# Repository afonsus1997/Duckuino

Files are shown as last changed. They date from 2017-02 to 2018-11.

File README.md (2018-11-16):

# 

### The truly open-source atmega32u4 ducky clone (V2.0)

## Info

Enter the duckuino, the fully open-source USB rubberducky clone based on the atmega32u4

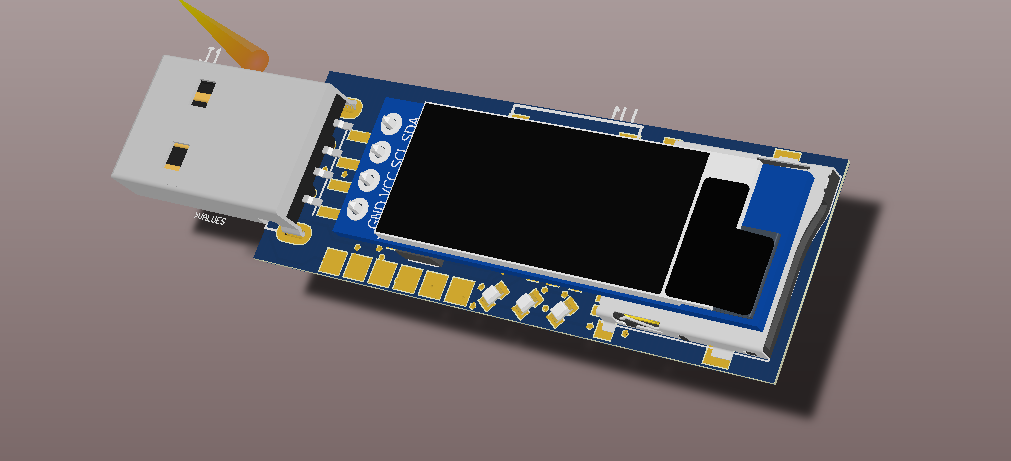
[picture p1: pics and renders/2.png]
Altium


## BOM

## PINMAP
PINMAP of the ATMEGA32u4

| PIN | ALT FUNCTION | OLED | Thumbwheel | LEDs | DIP Sw's | SD |
|:---:|:---:|:----:|:---:|:----:|:---:|:---:|
| D2  | SDA |  SDA | - | -  | - | - |
| D3  | SCL |  SCL | - | -  | - | - |
| D4  | A6 | -  | - | -  | - | CD/DAT3 (!CS!) |
| D5  | - | -  | - | -  | 4 | - |
| D6  | A7 | -  | - | LED1 | - | - |
| D7  | - | -  | - | LED2 | - | - |
| D8  | A8 | -  | Center | -  | - | - |
| D9  | A9 | -  | - | -  | 1 (Boot) | - |
| D10 | A10 | -  | - | -  | 2 | - |
| D11 | - | -  | Right | -  | - | - |
| D12 | - | -  | Left | -  | - | - |
| D13 | - | -  | - | -  | 3 | - |
| D14 | - | -  | - | -  | - | DAT0 (D0) |
| D15 | - | -  | - | -  | - | CLK (SCLK) |
| D16 | - | -  | - | -  | - | CMD (DI) |

## Renders & Pictures

### V2.0 Altium Renders

Altium

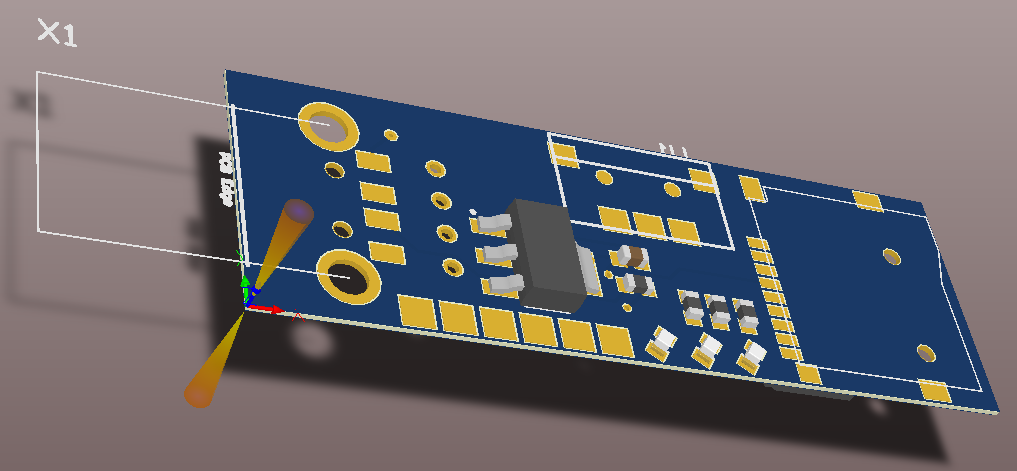
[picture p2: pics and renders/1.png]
Altium2


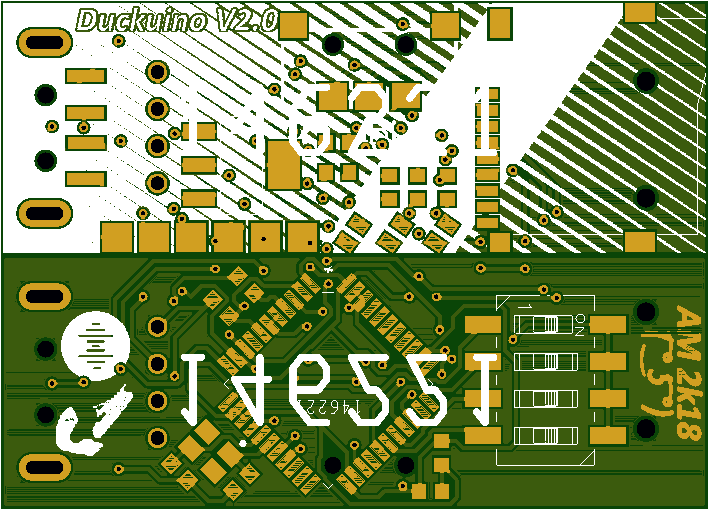
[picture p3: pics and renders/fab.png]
Fab


## Old Version Renders & Pictures

### V0.1 Photos
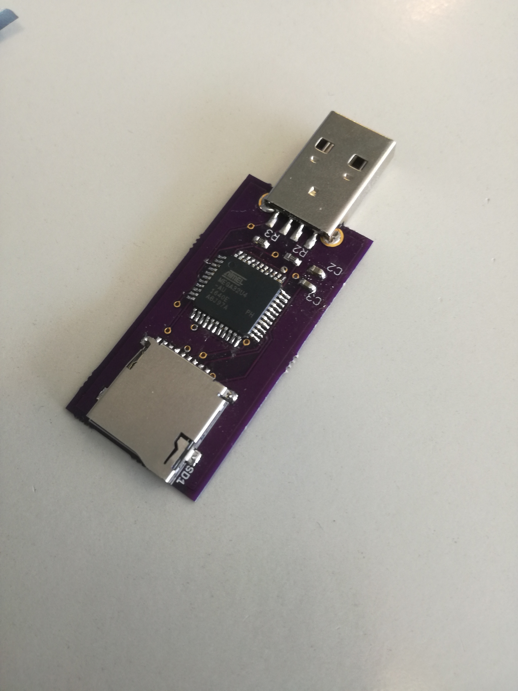
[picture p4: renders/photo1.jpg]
Soldered1


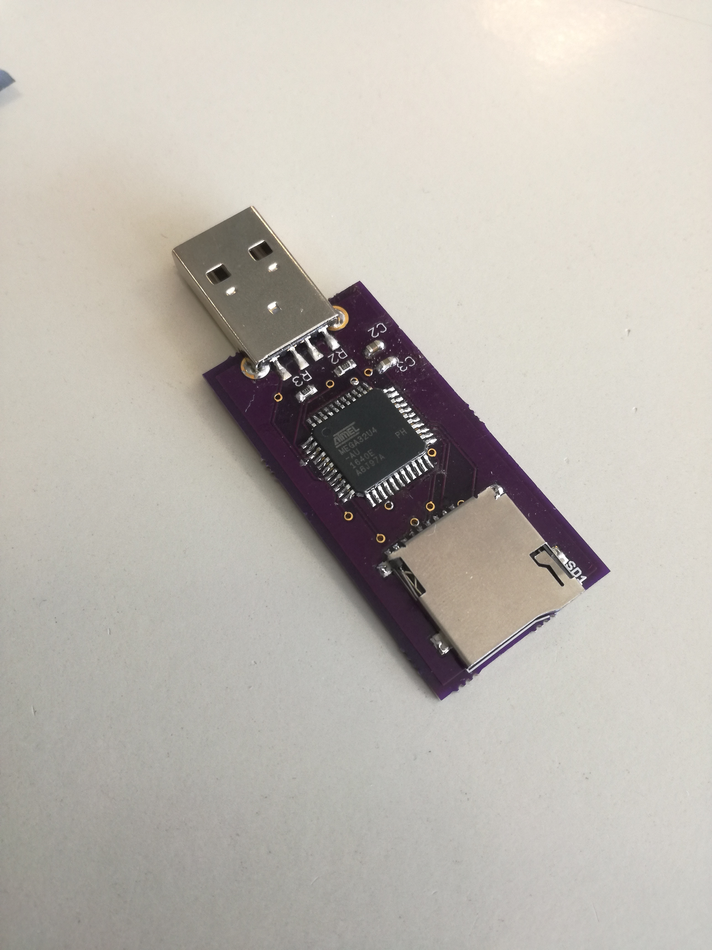
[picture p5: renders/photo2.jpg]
Soldered2


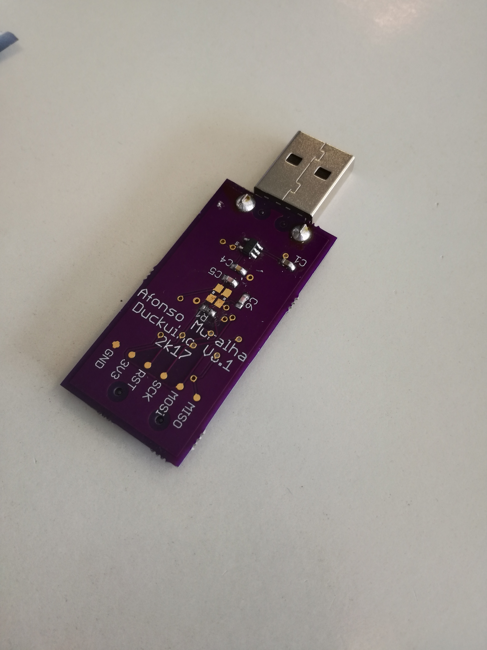
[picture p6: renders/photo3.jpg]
Soldered3


### V0.1 Renders
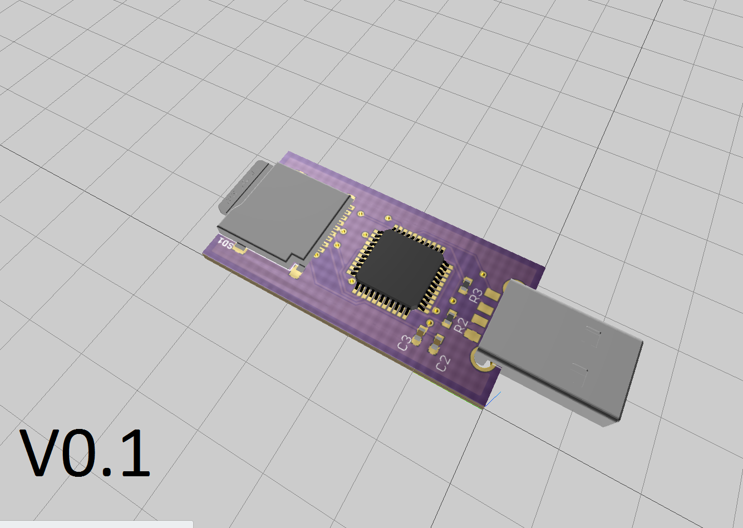
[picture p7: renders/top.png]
Render1


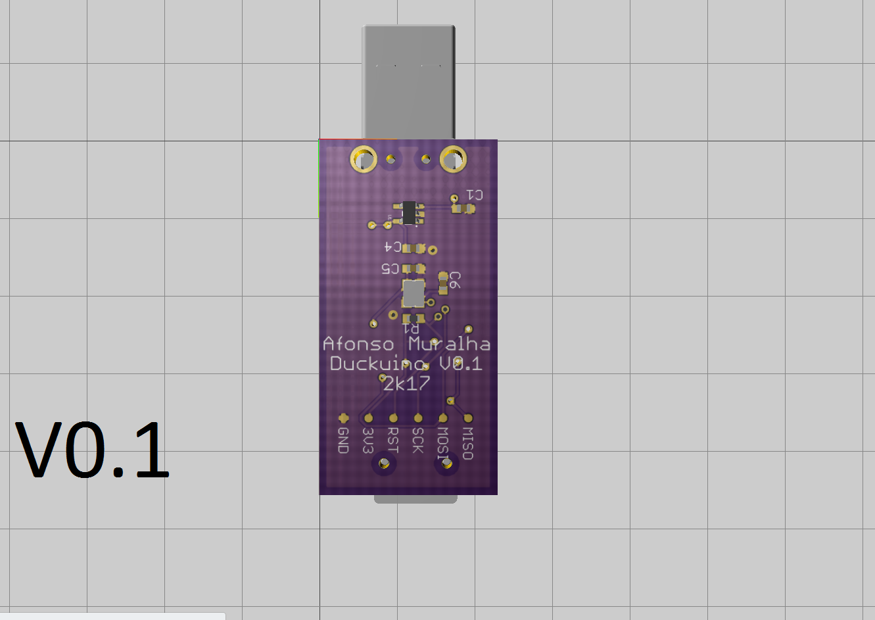
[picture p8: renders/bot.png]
Render2


### V0.1 Eagle Renders
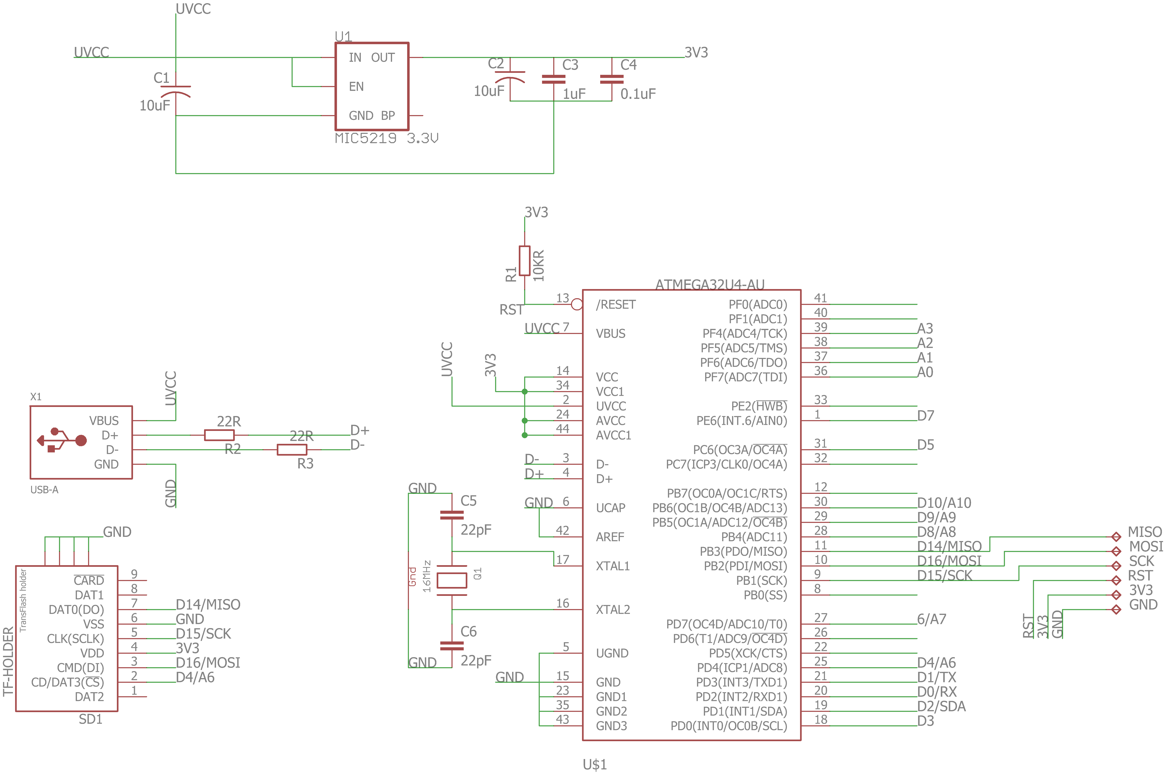
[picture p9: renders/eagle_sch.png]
Eagle1


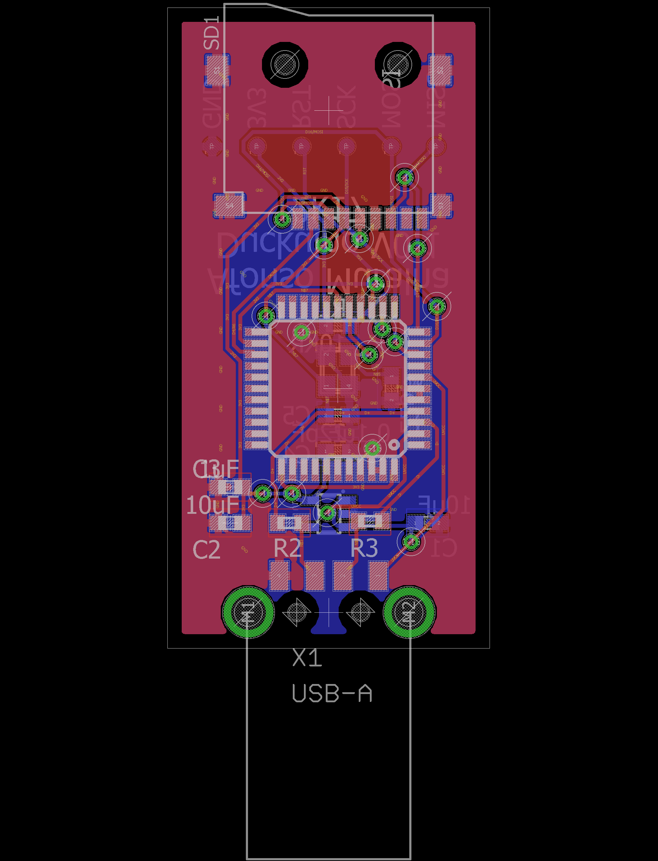
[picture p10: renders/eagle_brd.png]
Eagle2


### V0.1 PCB pictures
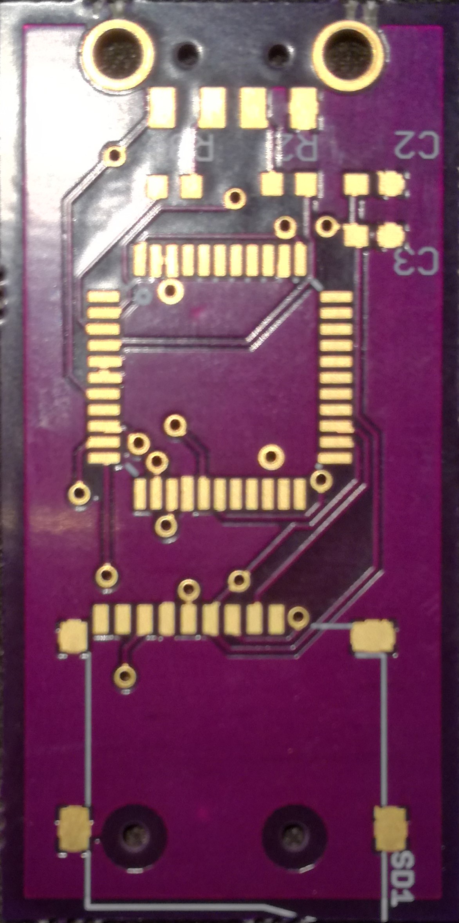
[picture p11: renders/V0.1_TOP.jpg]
PCB1
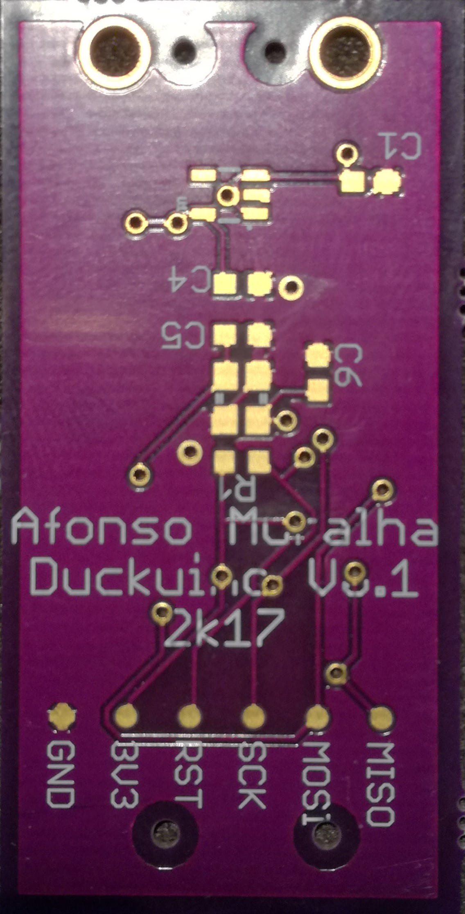
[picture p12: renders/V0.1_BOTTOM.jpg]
PCB2


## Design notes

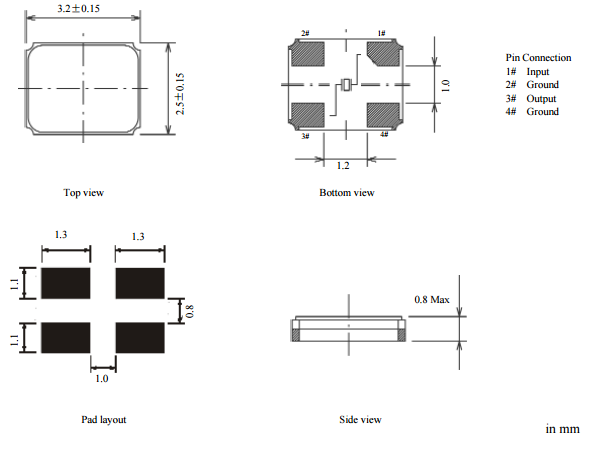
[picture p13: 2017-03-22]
XTALpinout.png

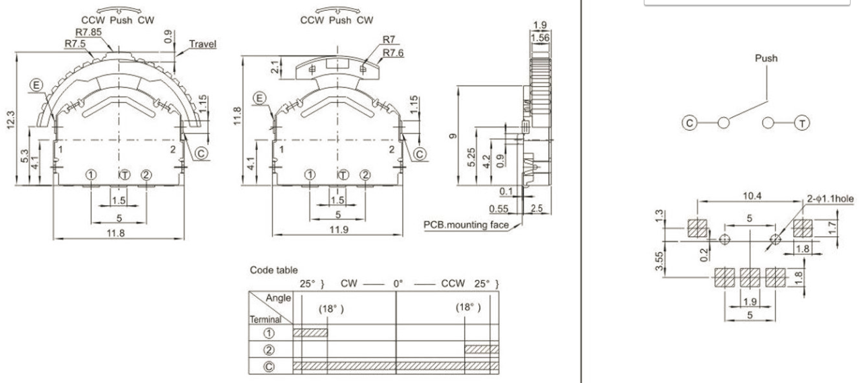
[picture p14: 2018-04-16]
slide pinout.png

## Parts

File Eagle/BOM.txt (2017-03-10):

Duckuino BOM

Part Value         Device            Package                                                                                                            
3V3  TPTP11R       TPTP11R           TP11R                                                                                                               
C1   10uF          C-USC0603         C0603                                                                                                         
C2   10uF          C-USC0603         C0603                                                                                                            
C3   1uF           C-EUC0603         C0603                                                                                                          
C4   0.1uF/100nF   C-EUC0603         C0603                                                                                                             
C5   22pF          C-EUC0603         C0603                                                                                                           
C6   22pF          C-EUC0603         C0603                                                                                                                                                                                                                              
Q1   16MHz         XTAL-4-3225       NX3225                                                                                                    
R1   10KR          RR0603            R0603                                                                                                               
R2   22R           RR0603            R0603                                                                                                              
R3   22R           RR0603            R0603                                                                                                                                                                                                                               
SD1  TF-HOLDER     TF-HOLDER         TF-PULL         
U$1  ATMEGA32U4-AU ATMEGA32U4-AU     TQFP44                                                                                                
U1   MIC5219 3.3V  V_REG_MIC52193.3V SOT23-5                                                                                                                      
X1   USB-A         USB-A

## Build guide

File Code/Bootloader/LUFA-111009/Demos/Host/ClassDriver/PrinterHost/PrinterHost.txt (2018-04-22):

/** \file
 *
 *  This file contains special DoxyGen information for the generation of the main page and other special
 *  documentation pages. It is not a project source file.
 */

/** \mainpage Printer Host Demo
 *
 *  \section Sec_Compat Demo Compatibility:
 *
 *  The following list indicates what microcontrollers are compatible with this demo.
 *
 *  - Series 7 USB AVRs (AT90USBxxx7)
 *
 *  \section Sec_Info USB Information:
 *
 *  The following table gives a rundown of the USB utilization of this demo.
 *
 *  <table>
 *   <tr>
 *    <td><b>USB Mode:</b></td>
 *    <td>Host</td>
 *   </tr>
 *   <tr>
 *    <td><b>USB Class:</b></td>
 *    <td>Printer Device</td>
 *   </tr>
 *   <tr>
 *    <td><b>USB Subclass:</b></td>
 *    <td>Bidirectional Protocol</td>
 *   </tr>
 *   <tr>
 *    <td><b>Relevant Standards:</b></td>
 *    <td>USBIF Printer Class Specification \n
 *        PCL Language Specification</td>
 *   </tr>
 *   <tr>
 *    <td><b>Usable Speeds:</b></td>
 *    <td>Low Speed Mode \n
 *        Full Speed Mode</td>
 *   </tr>
 *  </table>
 *
 *  \section Sec_Description Project Description:
 *
 *  Printer host demonstration application. This gives a simple reference
 *  application for implementing a USB Printer host, for USB printers using
 *  the bidirectional data encapsulation protocol and PCL language.
 *
 *  Upon connection of a compatible printer, the printer's device ID is sent
 *  to the AVR's serial port, and a simple test page is printed using the PCL
 *  printer language.
 *
 *  \section Sec_Options Project Options
 *
 *  The following defines can be found in this demo, which can control the demo behaviour when defined, or changed in value.
 *
 *  <table>
 *   <tr>
 *    <td>
 *     None
 *    </td>
 *   </tr>
 *  </table>
 */

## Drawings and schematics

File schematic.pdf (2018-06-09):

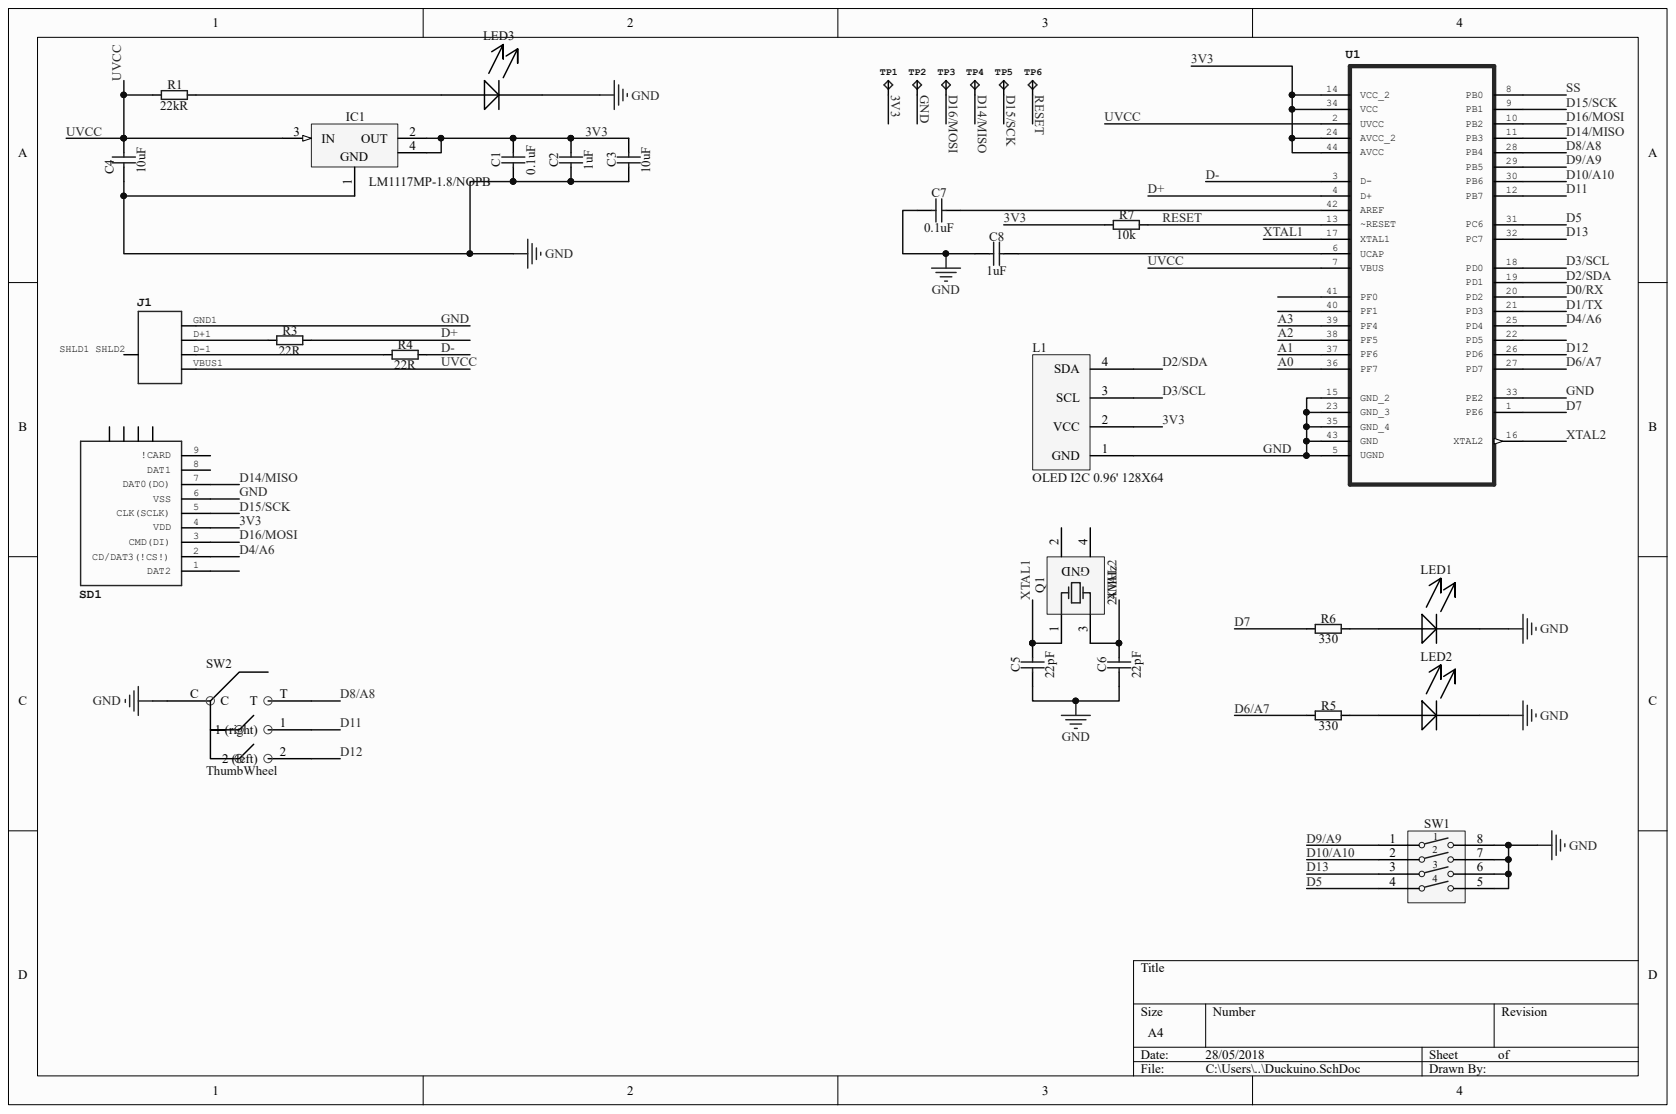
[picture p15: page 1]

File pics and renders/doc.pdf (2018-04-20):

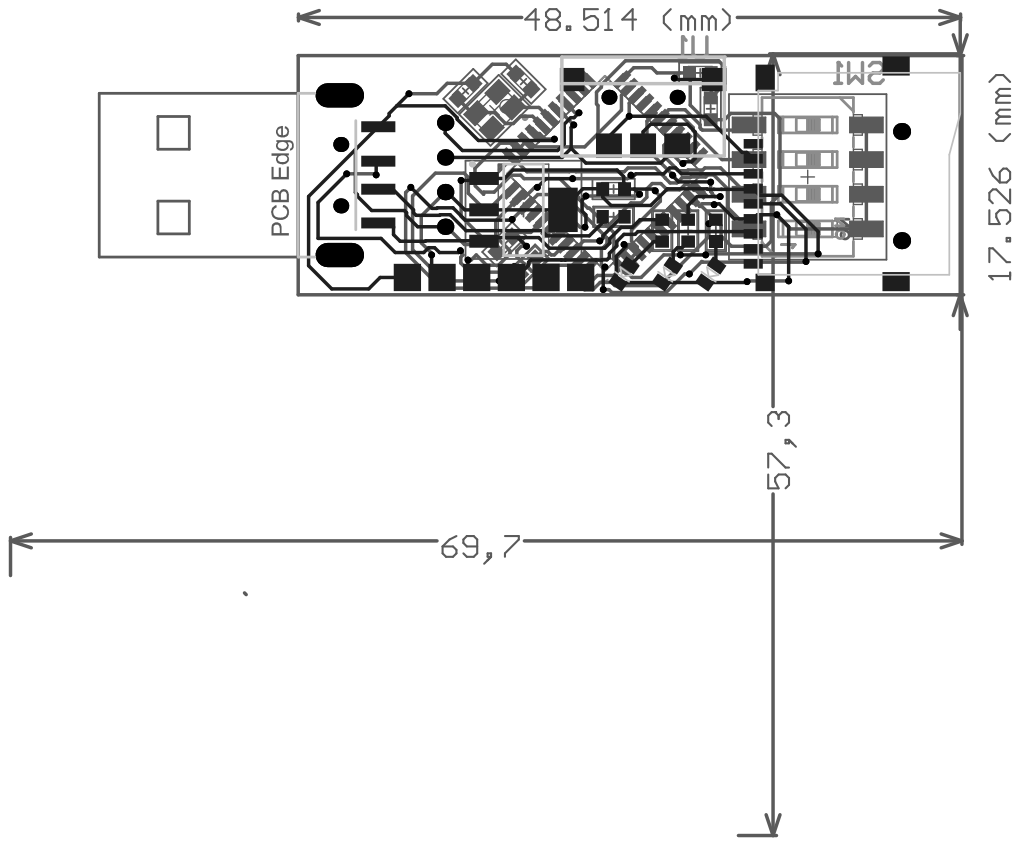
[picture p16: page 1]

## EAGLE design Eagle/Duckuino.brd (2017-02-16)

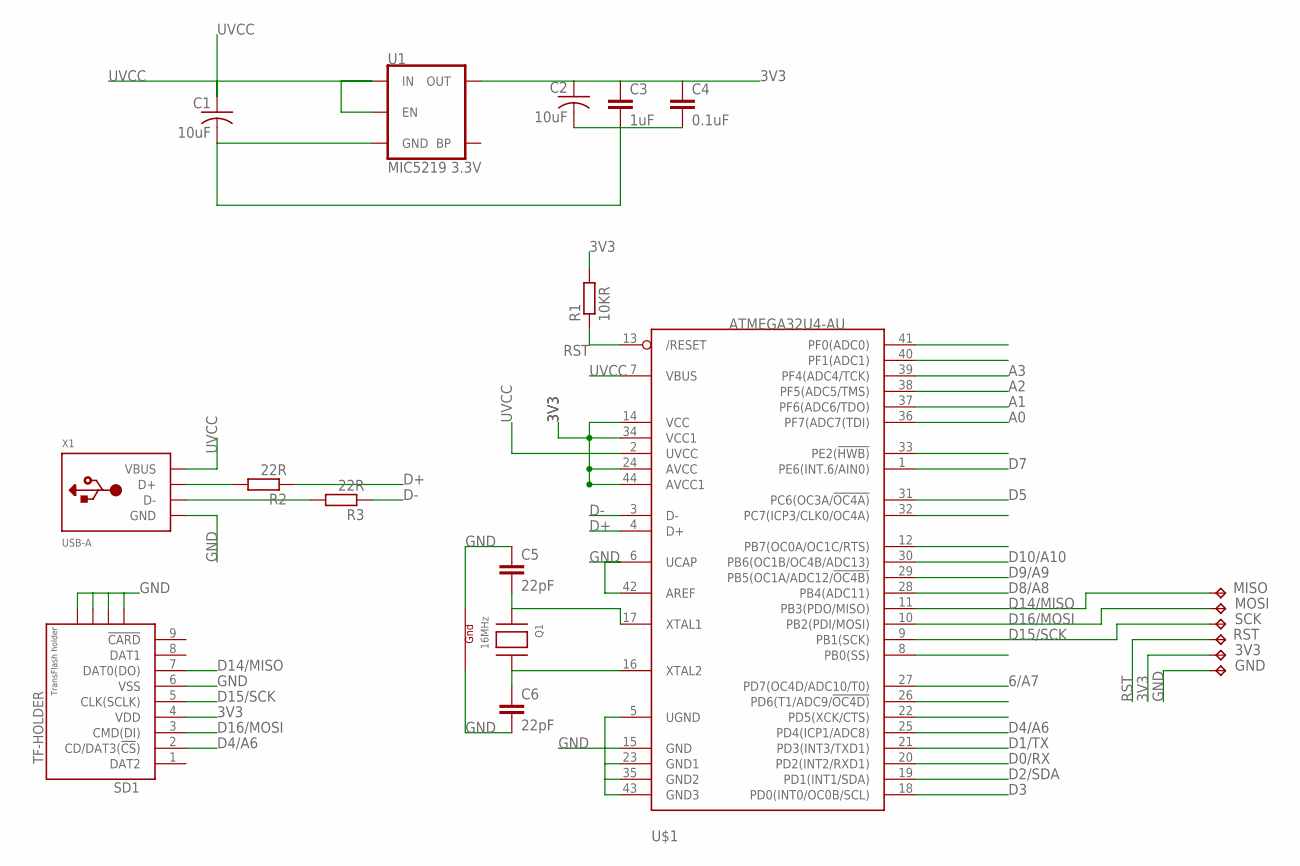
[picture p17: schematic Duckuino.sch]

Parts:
3V3: TPTP11R; TP11R
C1, C2: 10uF; C0603
C3: 1uF; C0603
C4: 0.1uF; C0603
C5, C6: 22pF; C0603
GND: TPTP11R; TP11R
MISO: TPTP11R; TP11R
MOSI: TPTP11R; TP11R
Q1: 16MHz; NX3225
R1: 10KR; R0603
R2, R3: 22R; R0603
RST: TPTP11R; TP11R
SCK: TPTP11R; TP11R
SD1: TF-HOLDER; TF-PULL
U1: MIC5219 3.3V; SOT23-5
U$1: ATMEGA32U4-AU; TQFP44
X1: USB-A; MOLEX_480371000

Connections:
3V3: 3V3.TP, C2.1, C3.1, C4.1, R1.2, SD1.4 (VDD), U1.5 (OUT), U$1.14 (VCC), U$1.24 (AVCC), U$1.34 (VCC1), U$1.44 (AVCC1)
6/A7: U$1.27 (PD7(OC4D/ADC10/T0))
A0: U$1.36 (PF7(ADC7(TDI))
A1: U$1.37 (PF6(ADC6/TDO))
A2: U$1.38 (PF5(ADC5/TMS))
A3: U$1.39 (PF4(ADC4/TCK))
D0/RX: U$1.20 (PD2(INT2/RXD1))
D1/TX: U$1.21 (PD3(INT3/TXD1))
D2/SDA: U$1.19 (PD1(INT1/SDA))
D3: U$1.18 (PD0(INT0/OC0B/SCL))
D4/A6: SD1.2 (CD/DAT3(!CS!)), U$1.25 (PD4(ICP1/ADC8))
D5: U$1.31 (PC6(OC3A/!OC4A))
D7: U$1.1 (PE6(INT.6/AIN0))
D8/A8: U$1.28 (PB4(ADC11))
D9/A9: U$1.29 (PB5(OC1A/ADC12/!OC4B))
D10/A10: U$1.30 (PB6(OC1B/OC4B/ADC13))
D14/MISO: MISO.TP, SD1.7 (DAT0(DO)), U$1.11 (PB3(PDO/MISO))
D15/SCK: SCK.TP, SD1.5 (CLK(SCLK)), U$1.9 (PB1(SCK))
D16/MOSI: MOSI.TP, SD1.3 (CMD(DI)), U$1.10 (PB2(PDI/MOSI))
D+: R2.1, U$1.4 (D+)
D-: R3.1, U$1.3 (D-)
GND: C1.2, C2.2, C3.2, C4.2, C5.1, C6.2, GND.TP, Q1.2 (G2), Q1.4 (G1), SD1.6 (VSS), SD1.S1, SD1.S2, SD1.S3, SD1.S4, U1.2 (GND), U$1.5 (UGND), U$1.6 (UCAP), U$1.15 (GND), U$1.23 (GND1), U$1.35 (GND2), U$1.42 (AREF), U$1.43 (GND3), X1.4 (GND)
unnamed: R2.2, X1.3 (D+)
unnamed: R3.2, X1.2 (D-)
unnamed: C6.1, Q1.3 (X2), U$1.16 (XTAL2)
unnamed: C5.2, Q1.1 (X1), U$1.17 (XTAL1)
RST: R1.1, RST.TP, U$1.13 (/RESET)
UVCC: C1.1, U1.1 (IN), U1.3 (EN), U$1.2 (UVCC), U$1.7 (VBUS), X1.1 (VBUS)

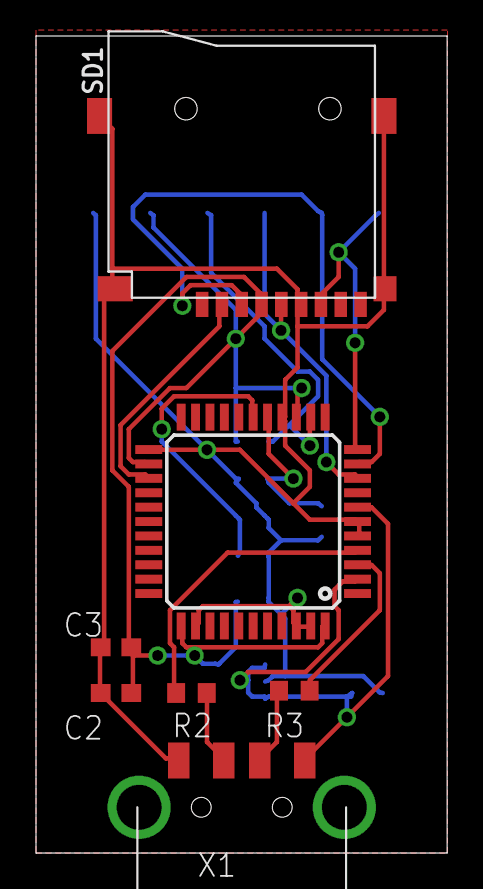
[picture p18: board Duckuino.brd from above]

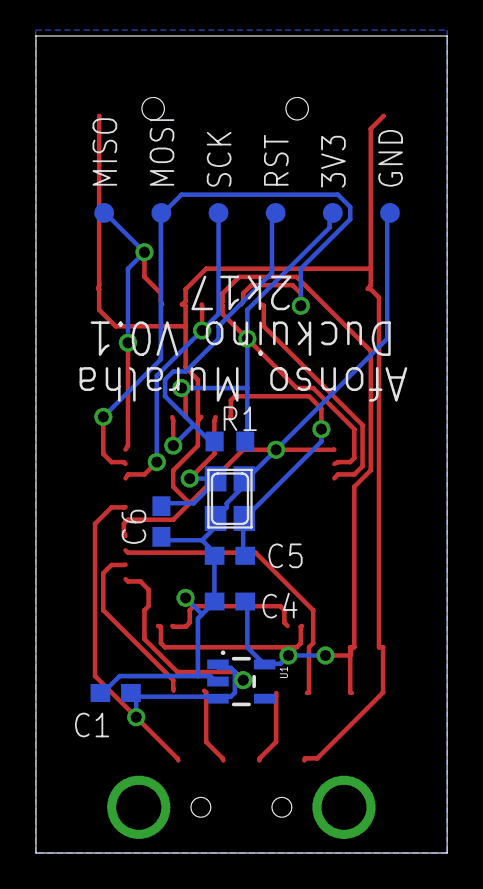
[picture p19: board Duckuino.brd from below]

Board: 2 copper layers, 22.8 x 45.4 mm, 20 parts (13 on the bottom side), 14 nets.

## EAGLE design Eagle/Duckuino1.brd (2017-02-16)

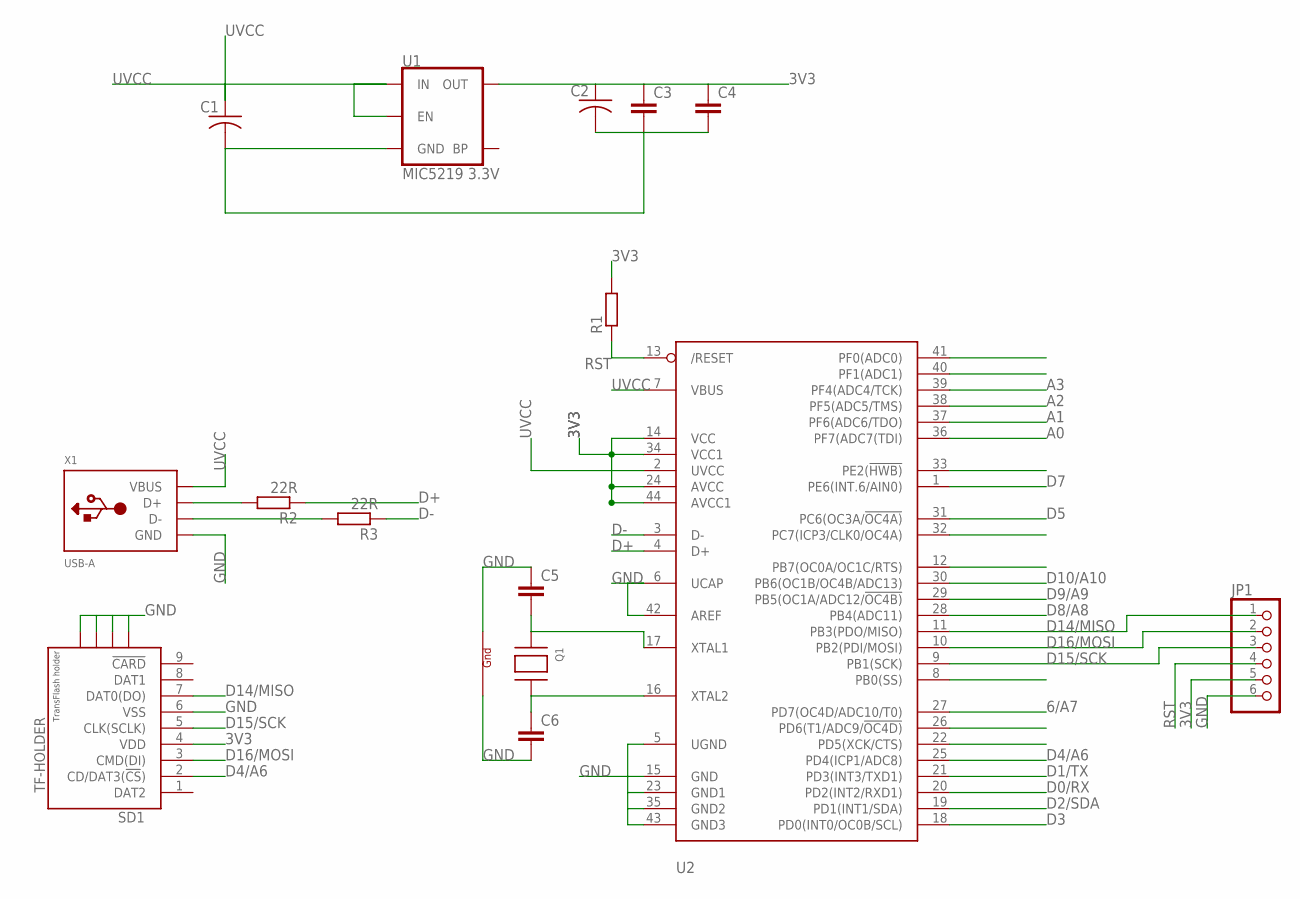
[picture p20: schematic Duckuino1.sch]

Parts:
C1, C2: C-USC0603; C0603
C3, C4, C5, C6: C-EUC0603; C0603
JP1: PINHD-1X6; 1X06
Q1: XTAL-4-3225; NX3225
R1: RR0603; R0603
R2, R3: 22R; R0603
SD1: TF-HOLDER; TF-PULL
U1: MIC5219 3.3V; SOT23-5
U2: ATMEGA32U4-AU; TQFP44
X1: USB-A; MOLEX_480371000

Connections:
3V3: C2.1, C3.1, C4.1, JP1.5, R1.2, SD1.4 (VDD), U1.5 (OUT), U2.14 (VCC), U2.24 (AVCC), U2.34 (VCC1), U2.44 (AVCC1)
6/A7: U2.27 (PD7(OC4D/ADC10/T0))
A0: U2.36 (PF7(ADC7(TDI))
A1: U2.37 (PF6(ADC6/TDO))
A2: U2.38 (PF5(ADC5/TMS))
A3: U2.39 (PF4(ADC4/TCK))
D0/RX: U2.20 (PD2(INT2/RXD1))
D1/TX: U2.21 (PD3(INT3/TXD1))
D2/SDA: U2.19 (PD1(INT1/SDA))
D3: U2.18 (PD0(INT0/OC0B/SCL))
D4/A6: SD1.2 (CD/DAT3(!CS!)), U2.25 (PD4(ICP1/ADC8))
D5: U2.31 (PC6(OC3A/!OC4A))
D7: U2.1 (PE6(INT.6/AIN0))
D8/A8: U2.28 (PB4(ADC11))
D9/A9: U2.29 (PB5(OC1A/ADC12/!OC4B))
D10/A10: U2.30 (PB6(OC1B/OC4B/ADC13))
D14/MISO: JP1.1, SD1.7 (DAT0(DO)), U2.11 (PB3(PDO/MISO))
D15/SCK: JP1.3, SD1.5 (CLK(SCLK)), U2.9 (PB1(SCK))
D16/MOSI: JP1.2, SD1.3 (CMD(DI)), U2.10 (PB2(PDI/MOSI))
D+: R2.1, U2.4 (D+)
D-: R3.1, U2.3 (D-)
GND: C1.2, C2.2, C3.2, C4.2, C5.1, C6.2, JP1.6, Q1.2 (G2), Q1.4 (G1), SD1.6 (VSS), SD1.S1, SD1.S2, SD1.S3, SD1.S4, U1.2 (GND), U2.5 (UGND), U2.6 (UCAP), U2.15 (GND), U2.23 (GND1), U2.35 (GND2), U2.42 (AREF), U2.43 (GND3), X1.4 (GND)
unnamed: R2.2, X1.3 (D+)
unnamed: R3.2, X1.2 (D-)
unnamed: C6.1, Q1.3 (X2), U2.16 (XTAL2)
unnamed: C5.2, Q1.1 (X1), U2.17 (XTAL1)
RST: JP1.4, R1.1, U2.13 (/RESET)
UVCC: C1.1, U1.1 (IN), U1.3 (EN), U2.2 (UVCC), U2.7 (VBUS), X1.1 (VBUS)

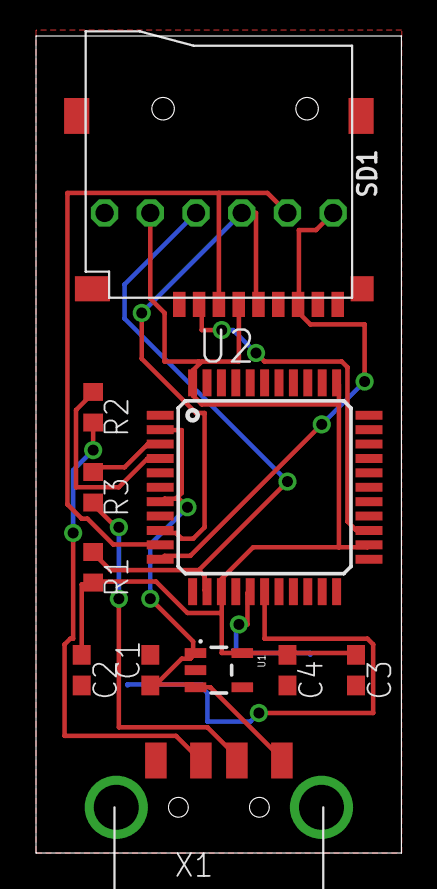
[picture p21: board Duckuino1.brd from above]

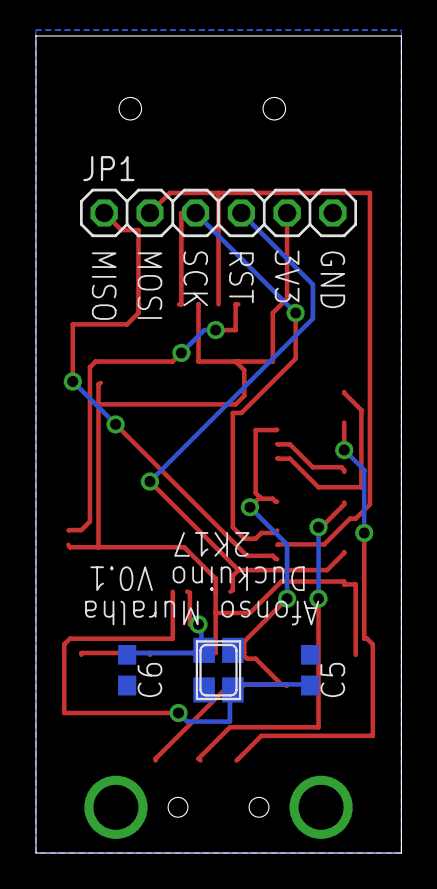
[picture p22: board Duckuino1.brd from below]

Board: 2 copper layers, 20.3 x 45.4 mm, 15 parts (4 on the bottom side), 14 nets.

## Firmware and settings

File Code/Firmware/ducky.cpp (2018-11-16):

#include "ducky.h"
#include "Keyboard_PT.h"
#include <EEPROM.h>
//#include <Keyboard.h>
//#include "Mouse.h"
//#define debug
File payload;

char* buf = malloc(sizeof(char)*buffersize);
char *cmd = malloc(sizeof(char)*300);
char* repeatBuffer = malloc(sizeof(char) * 12);

int keystatus = 0;
int eeaddr = 0;
int ispt = 0;
int delay_val;
int bufSize = 0;
int defaultDelay = 5;
int defaultCharDelay = 5;
bool ledOn = true;
int rMin = -100;
int rMax = 100;

//char *cmd;
//char *test;


int getSpace(int start, int end) {
	for (int i = start; i<end; i++) {
		if (buf[i] == ' ') return i;
	}
	return -1;
}

bool equals(char* strA, int start, int end, char* strB, int strLen) {
	if (end - start != strLen) return false;
	for (int i = 0; i<strLen; i++) {
		if (strA[start + i] != strB[i]) return false;
	}
	return true;
}

int toPositive(int num) {
	if (num < 0) return num * (-1);
	else return num;
}

bool equalsBuffer(int start, int end, char* str) { return equals(buf, start, end, str, String(str).length()); }

int getInt(char* str, int pos) {
	if (equals(str, pos + 1, pos + 7, "RANDOM", 6)) {
		return random(rMin, rMax);
	}
	else {
		return String(str).substring(pos + 1, pos + 6).toInt();
	}
}

void KeyboardWrite(uint8_t c) {
	Keyboard.press(c);
	delay(defaultCharDelay);
	Keyboard.release(c);
	//delay(10);
}

void KeyboardWrite_pt(uint8_t c) {
	Keyboard.press_pt(c);
	delay(defaultCharDelay);
	Keyboard.release_pt(c);
	//delay(10);
}




void runLine() {
#ifdef debug
	Serial.println("run: '" + String(buf).substring(0, bufSize) + "' (" + (String)bufSize + ")");
#endif
	int space = getSpace(0, bufSize);
	
	Serial.print("LINE:");  Serial.println(buf);
	oled.clear();
	oled.println("====== RUNNING ======"); oled.println(); oled.print(buf);

	char *arg;
	char *newArray = buf;


	cmd = strtok(buf, " ");



	if (space == -1) runCommand(0, bufSize);
	else {
		if (equalsBuffer(0, space, "DEFAULTDELAY") || equalsBuffer(0, space, "DEFAULT_DELAY")) defaultDelay = getInt(buf, space);
		else if (equalsBuffer(0, space, "DEFAULTCHARDELAY") || equalsBuffer(0, space, "DEFAULT_CHAR_DELAY")) defaultCharDelay = getInt(buf, space);
		else if (equals(buf, 0, space, "DELAY", strlen("DELAY"))) {
			cmd = strtok(NULL, " ");
			delay_val = atoi(cmd);

			//oled.println("DELAY"); oled.println(delay_val);
			delay(delay_val);

		}
		else if (equals(buf, 0, space, "STRING", strlen("STRING"))) {
			//oled.println("STRING");
			for (int i = space + 1; i < bufSize; i++) { if (ispt) { KeyboardWrite_pt(buf[i]); } else  KeyboardWrite(buf[i]);
			}
		}


		else if (equalsBuffer(0, space, "MOUSE")) {
			int nSpace = getSpace(space + 1, bufSize);
			int x = getInt(buf, space);
			int y = getInt(buf, nSpace);
			Mouse.move(x, y);
#ifdef debug
			Serial.println("Move mouse " + (String)x + " " + (String)y);
#endif
		}
		else if (equalsBuffer(0, space, "SCROLL")) Mouse.move(0, 0, getInt(buf, space));
		else if (equalsBuffer(0, space, "RANDOMMIN")) rMin = getInt(buf, space);
		else if (equalsBuffer(0, space, "RANDOMMAX")) rMax = getInt(buf, space);
		else if (equalsBuffer(0, space, "REM") || equalsBuffer(0, space, "REPEAT")) {}
		else {
			//runCommand(0, space);
			//for (int k=0; k < bufSize; k++) { oled.print(char(buf[k])); } 
			int nSpace;


			while (cmd != NULL) {

				runCommand(0, 0);
				cmd = strtok('\0', " \n");


			}
		}
	}

	Keyboard.releaseAll();
	delay(defaultDelay);
}

int checkKey() {
	if (strcmp(cmd, "ENTER") == 0) { Keyboard.press(KEY_RETURN); return 1; }
	else if (strcmp(cmd, "GUI") == 0) { Keyboard.press(KEY_LEFT_GUI); return 1; }//Keyboard.press(KEY_LEFT_GUI);
	else if (strcmp(cmd, "SHIFT") == 0) { Keyboard.press(KEY_LEFT_SHIFT); return 1; }
	else if (strcmp(cmd, "ALT") == 0 || strcmp(cmd, "ALT_LEFT") == 0 || strcmp(cmd, "ALTLEFT") == 0) { Keyboard.press(KEY_LEFT_ALT); return 1; }
	else if (strcmp(cmd, "ALT_RIGHT") == 0 || strcmp(cmd, "ALTRIGHT") == 0) { Keyboard.press(KEY_RIGHT_ALT); return 1; }
	else if (strcmp(cmd, "CTRL") == 0 || strcmp(cmd, "CONTROL") == 0) { Keyboard.press(KEY_LEFT_CTRL); return 1; }
	else if (strcmp(cmd, "CAPSLOCK") == 0) { Keyboard.press(KEY_CAPS_LOCK); return 1; }
	else if (strcmp(cmd, "DELETE") == 0) { Keyboard.press(KEY_DELETE); return 1; }
	else if (strcmp(cmd, "END") == 0) { Keyboard.press(KEY_END); return 1; }
	else if (strcmp(cmd, "ESC") == 0 || strcmp(cmd, "ESCAPE") == 0) {Keyboard.press(KEY_ESC);return 1;}
	else if (strcmp(cmd, "HOME") == 0) { Keyboard.press(KEY_HOME); return 1; return 1; }
	else if (strcmp(cmd, "INSERT") == 0) { Keyboard.press(KEY_INSERT); return 1; }
	else if (strcmp(cmd, "PAGEUP") == 0) {Keyboard.press(KEY_PAGE_UP);return 1;}
	else if (strcmp(cmd, "PAGEDOWN") == 0) { Keyboard.press(KEY_PAGE_DOWN); return 1; }
	else if (strcmp(cmd, "SPACE") == 0) { Keyboard.press(' '); return 1; }
	else if (strcmp(cmd, "TAB") == 0) { Keyboard.press(KEY_TAB); return 1; }
	else if (strcmp(cmd, "BACKSPACE") == 0) { Keyboard.press(KEY_BACKSPACE); return 1; }

	if (strcmp(cmd, "UP") == 0 || strcmp(cmd, "UPARROW") == 0) { Keyboard.press(KEY_UP_ARROW); return 1; }
	else if (strcmp(cmd, "DOWN") == 0 || strcmp(cmd, "DOWNARROW") == 0) { Keyboard.press(KEY_DOWN_ARROW); return 1; }
	else if (strcmp(cmd, "LEFT") == 0 || strcmp(cmd, "LEFTARROW") == 0) { Keyboard.press(KEY_LEFT_ARROW); return 1; }
	//else if (strcmp(cmd, "RIGHT") == 0 || strcmp(cmd, "RIGHTARROW") == 0) {Keyboard.press(KEY_RIGHT_ARROW); return 1;}

	//else if (strcmp(cmd, "PRINTSCREEN") == 0) { Keyboard.press(PRINTSCREEN); return 1; }
	
	else return 0;

}

int checkF() {
	if (strcmp(cmd, "F1") == 0) { Keyboard.press(KEY_F1); return 1; }
	
	else if (strcmp(cmd, "RIGHT") == 0 || strcmp(cmd, "RIGHTARROW") == 0) {Keyboard.press(KEY_RIGHT_ARROW); return 1;}

	else if (strcmp(cmd, "PRINTSCREEN") == 0) { Keyboard.press(PRINTSCREEN); return 1; }

	
	
	else if (strcmp(cmd, "F2") == 0) { Keyboard.press(KEY_F2); return 1; }
	else if (strcmp(cmd, "F3") == 0) { Keyboard.press(KEY_F3); return 1; }
	else if (strcmp(cmd, "F4") == 0) { Keyboard.press(KEY_F4); return 1; }
	else if (strcmp(cmd, "F5") == 0) { Keyboard.press(KEY_F5); return 1; }
	else if (strcmp(cmd, "F6") == 0) { Keyboard.press(KEY_F6); return 1; }
	else if (strcmp(cmd, "F7") == 0) { Keyboard.press(KEY_F7); return 1; }
	else if (strcmp(cmd, "F8") == 0) { Keyboard.press(KEY_F8); return 1; }
	else if (strcmp(cmd, "F9") == 0) { Keyboard.press(KEY_F9); return 1; }
	else if (strcmp(cmd, "F10") == 0) { Keyboard.press(KEY_F10); return 1; }
	else if (strcmp(cmd, "F11") == 0) { Keyboard.press(KEY_F11); return 1; }
	else if (strcmp(cmd, "F12") == 0) { Keyboard.press(KEY_F12); return 1; }
	else return 0;
}
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

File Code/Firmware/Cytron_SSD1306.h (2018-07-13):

/*********************************************************************
This is a library for Monochrome OLEDs based on SSD1306 drivers for I2C 
communication only.

Modified from Adafruit SSD1306 Library


The original library is Written by Limor Fried/Ladyada  for Adafruit Industries.
BSD license, check license.txt for more information
All text above, and the splash screen below must be included in any redistribution
*********************************************************************/
#ifndef _CYTRON_SSD1306_H_
#define _CYTRON_SSD1306_H_
 
#include "AvrI2c.h"
#include <SSD1306Ascii.h>

/*#if ARDUINO >= 100
 #include "Arduino.h"
 #define WIRE_WRITE Wire.write
#else
 #include "WProgram.h"
  #define WIRE_WRITE Wire.send
#endif

#if defined(__SAM3X8E__)
 typedef volatile RwReg PortReg;
 typedef uint32_t PortMask;
 #define HAVE_PORTREG
#elif defined(ARDUINO_ARCH_SAMD)
// not supported
#elif defined(ESP8266) || defined(ARDUINO_STM32_FEATHER)
  typedef volatile uint32_t PortReg;
  typedef uint32_t PortMask;
#else
  typedef volatile uint8_t PortReg;
  typedef uint8_t PortMask;
 #define HAVE_PORTREG
#endif

#ifdef __AVR__
 #include <avr/pgmspace.h>
#elif defined(ESP8266)
 #include <pgmspace.h>
#endif
//#include "Adafruit_GFX.h"
#include "glcdfont.c"
#include "ArialMT_Plain.h"
#include <Print.h>
*/

// Many (but maybe not all) non-AVR board installs define macros
// for compatibility with existing PROGMEM-reading AVR code.
// Do our own checks and defines here for good measure...
/*
#ifndef pgm_read_byte
 #define pgm_read_byte(addr) (*(const unsigned char *)(addr))
#endif
#ifndef pgm_read_word
 #define pgm_read_word(addr) (*(const unsigned short *)(addr))
#endif
#ifndef pgm_read_dword
 #define pgm_read_dword(addr) (*(const unsigned long *)(addr))
#endif
*/
// Pointers are a peculiar case...typically 16-bit on AVR boards,
// 32 bits elsewhere.  Try to accommodate both...
/*
#if !defined(__INT_MAX__) || (__INT_MAX__ > 0xFFFF)
 #define pgm_read_pointer(addr) ((void *)pgm_read_dword(addr))
#else
 #define pgm_read_pointer(addr) ((void *)pgm_read_word(addr))
#endif

#ifndef min
#define min(a,b) (((a) < (b)) ? (a) : (b))
#endif

#ifndef _swap_int16_t
#define _swap_int16_t(a, b) { int16_t t = a; a = b; b = t; }
#endif
*/
//#define BLACK 0
//#define WHITE 1
//#define INVERSE 2
#define NORMAL 0
#define INVERTED 1

#define SSD1306_I2C_ADDRESS   0x3C  // 011110+SA0+RW - 0x3C or 0x3D
// Address for 128x32 is 0x3C
// Address for 128x64 is 0x3D (default) or 0x3C (if SA0 is grounded)

/*=========================================================================
    SSD1306 Displays
    -----------------------------------------------------------------------
    The driver is used in multiple displays (128x64, 128x32, etc.).
    Select the appropriate display below to create an appropriately
    sized framebuffer, etc.

    SSD1306_128_64  128x64 pixel display

    SSD1306_128_32  128x32 pixel display

    SSD1306_96_16

    -----------------------------------------------------------------------*/
//   #define SSD1306_128_64
   #define SSD1306_128_32
//   #define SSD1306_96_16
/*=========================================================================*/

#if defined SSD1306_128_64 && defined SSD1306_128_32
  #error "Only one SSD1306 display can be specified at once in SSD1306.h"
#endif
#if !defined SSD1306_128_64 && !defined SSD1306_128_32 && !defined SSD1306_96_16
  #error "At least one SSD1306 display must be specified in SSD1306.h"
#endif

#if defined SSD1306_128_64
  #define SSD1306_LCDWIDTH                  128
  #define SSD1306_LCDHEIGHT                 64
#endif
 #if defined SSD1306_128_32
   #define SSD1306_LCDWIDTH                  128
   #define SSD1306_LCDHEIGHT                 32
 #endif
// #if defined SSD1306_96_16
//   #define SSD1306_LCDWIDTH                  96
//   #define SSD1306_LCDHEIGHT                 16
// #endif
/*
#define SSD1306_SETCONTRAST 0x81
#define SSD1306_DISPLAYALLON_RESUME 0xA4
#define SSD1306_DISPLAYALLON 0xA5
#define SSD1306_NORMALDISPLAY 0xA6
#define SSD1306_INVERTDISPLAY 0xA7
#define SSD1306_DISPLAYOFF 0xAE
#define SSD1306_DISPLAYON 0xAF

#define SSD1306_SETDISPLAYOFFSET 0xD3
#define SSD1306_SETCOMPINS 0xDA

#define SSD1306_SETVCOMDETECT 0xDB

#define SSD1306_SETDISPLAYCLOCKDIV 0xD5
#define SSD1306_SETPRECHARGE 0xD9

#define SSD1306_SETMULTIPLEX 0xA8

#define SSD1306_SETLOWCOLUMN 0x00
#define SSD1306_SETHIGHCOLUMN 0x10

#define SSD1306_SETSTARTLINE 0x40

#define SSD1306_MEMORYMODE 0x20
#define SSD1306_COLUMNADDR 0x21
#define SSD1306_PAGEADDR   0x22

#define SSD1306_COMSCANINC 0xC0
#define SSD1306_COMSCANDEC 0xC8

#define SSD1306_SEGREMAP 0xA0

#define SSD1306_CHARGEPUMP 0x8D

#define SSD1306_EXTERNALVCC 0x1
#define SSD1306_SWITCHCAPVCC 0x2
*/
// Scrolling #defines
#define SSD1306_ACTIVATE_SCROLL 0x2F
#define SSD1306_DEACTIVATE_SCROLL 0x2E
#define SSD1306_SET_VERTICAL_SCROLL_AREA 0xA3
#define SSD1306_RIGHT_HORIZONTAL_SCROLL 0x26
#define SSD1306_LEFT_HORIZONTAL_SCROLL 0x27
#define SSD1306_VERTICAL_AND_RIGHT_HORIZONTAL_SCROLL 0x29
#define SSD1306_VERTICAL_AND_LEFT_HORIZONTAL_SCROLL 0x2A


class Cytron_SSD1306 : public SSD1306Ascii {
 public:
  Cytron_SSD1306();

  /**
   * @brief Initialize the display controller.
   *
   * @param[in] dev A device initialization structure.
   * @param[in] i2cAddr The I2C address of the display controller.
   * @param[in] fastMode Fast 400 kHz mode if true else standard 100 kHz mode.
   */
  void begin(const DevType* dev = &Adafruit128x32, uint8_t i2cAddr = SSD1306_I2C_ADDRESS, bool fastMode = true) {
    m_nData = 0;
    m_i2cAddr = i2cAddr;

    m_i2c.begin(fastMode);
    init(dev);

    //default font is System5x7
    setFont(System5x7);
  }

  void invertDisplay(uint8_t i);

  void startscrollright(uint8_t start, uint8_t stop);
  void startscrollleft(uint8_t start, uint8_t stop);

  void startscrolldiagright(uint8_t start, uint8_t stop);
  void startscrolldiagleft(uint8_t start, uint8_t stop);
  void stopscroll(void);

  void dim(boolean dim);

  void drawPixel(int16_t x, int16_t y, uint16_t color);

  void writeByte(const uint8_t byte, uint8_t color=NORMAL);
  void drawBitmap(int16_t x, int16_t y, const uint8_t *bitmap, int16_t w, int16_t h, 
                  uint8_t color=NORMAL);
  void drawBitmap(int16_t x, int16_t y, const char *bitmap, int16_t w, int16_t h, 
                  uint8_t color=NORMAL){
                    drawBitmap(x, y, (const uint8_t *)bitmap, w, h, color);
                  }
  
protected:
  void writeDisplay(uint8_t b, uint8_t mode) {
    if ((m_nData && mode == SSD1306_MODE_CMD)) {
      m_i2c.stop();
      m_nData = 0;
    }
    if (m_nData == 0) {
      m_i2c.start((m_i2cAddr << 1) | I2C_WRITE);
      m_i2c.write(mode == SSD1306_MODE_CMD ? 0X00 : 0X40);
    }
    m_i2c.write(b);
    if (mode == SSD1306_MODE_RAM_BUF) {
      m_nData++; 
    }else {      
      m_i2c.stop();
      m_nData = 0;
    }
  }

private:
  AvrI2c m_i2c;
  uint8_t m_i2cAddr;
  uint8_t m_nData;
  
};
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

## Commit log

2017-02-16 Added main files for version 0.1
    [Duckuino.brd, Duckuino.sch, Duckuino1.brd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]
2017-03-10 Seprate Eagle folder in order to add altium files
    [Duckuino.brd, Duckuino.sch, Duckuino1.brd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]
2017-03-10 Added main Altium files and Libraries
    [Atmel_By_element14_Batch_1-00.PCBLIB, Atmel_By_element14_Batch_1-00.PrjPcb, Atmel_By_element14_Batch_1-00.SCHLIB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]
2017-03-10 Started working on schematics and edited some libraries
    [Duckuino.PcbDoc, Duckuino.SchDoc, Duckuinp.PrjPcb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]
2017-03-10 updated schematic and created more libs
    [Duckuino.PcbDoc, Duckuino.SchDoc, Tact-SW-lib.PcbLib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]
2017-03-15 Completed circuit and added pinmap to readme
    [DIPSW8.PcbLib, Duckuino.PcbDoc, Duckuino.SchDoc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]
2017-03-15 trying to fix markdown
    [Duckuino.PcbDoc, Duckuino.SchDoc, Duckuinp.PrjPcb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]
2017-03-16 Started testing pcb layout and added soldered pictures
    [Duckuino.PcbDoc, Duckuino.SchDoc, Tact-SW-lib2.PcbLib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]
2017-03-20 random tests
    [Duckuino.PcbDoc, Duckuino.SchDoc, Duckuinp.PrjPcb]
2018-04-15 redoing schematics, added new libs
    [Duckuino.PcbDoc, Duckuino.SchDoc]
2018-04-16 started routing, added lcd model
    [Duckuino.PcbDoc, Duckuino.SchDoc]
2018-04-18 finished routing, added 3d models
    [Duckuino.PcbDoc, Duckuino.SchDoc, sd.PCBLIB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]
2018-04-20 sent to fab
    [Duckuino.PcbDoc, Duckuinp.PrjPcb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]
2018-04-22 New custom bootloader
    [ConfiguringApps.txt]
2018-04-22 new readme, added pinouts
    [PinOut.csv, PinOut.xlsx]
2018-04-25 changed things around, moved to lighter libs
    [ConfiguringApps.txt]
2018-05-14 fixed schematic, started routing
    [Duckuino.PcbDoc, Duckuino.SchDoc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]
2018-05-24 did routing
    [Duckuino.PcbDoc]
2018-06-09 new xtal
    [Duckuino.GBL, Duckuino.GBO, Duckuino.GBS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]
2018-06-12 new silkscreen
    [Duckuino.PcbDoc, Duckuinp.PrjPcb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]
2018-06-16 sent new version to fab, testing white soldermask
    [Duckuino.PcbDoc, Duckuino.SchDoc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]
2018-11-16 edited readme
    [Atmel_By_element14_Batch_1-00.PCBLIB, Duckuino.PcbDoc]

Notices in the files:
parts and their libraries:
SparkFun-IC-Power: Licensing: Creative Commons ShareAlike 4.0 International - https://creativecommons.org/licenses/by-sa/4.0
